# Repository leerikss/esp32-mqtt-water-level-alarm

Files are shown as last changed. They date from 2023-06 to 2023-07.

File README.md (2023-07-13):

# esp32-mqtt-water-level-alarm

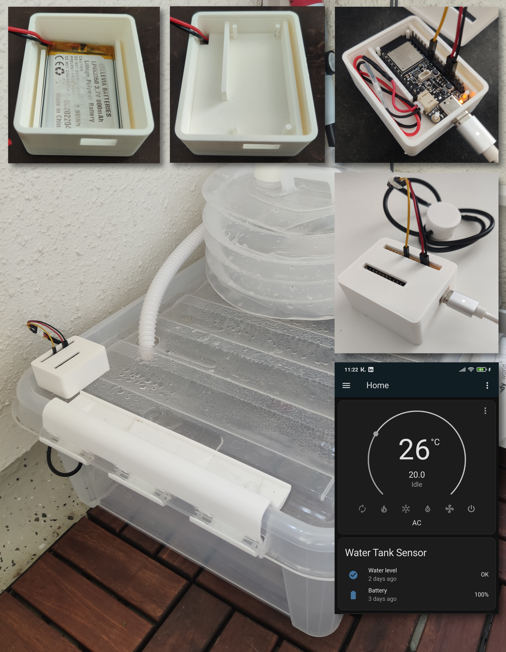
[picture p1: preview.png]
Device in actin with a 3D printed enclosure


I have a water tank on my balcony collecting condensation water from the AC.
To prevent potential water overflow, I made a little system that shuts down the AC if the tank gets too full.
The system consists of
1) an esp32 board with a liquid level sensor powered by a LiPo battery, sending MQTT messages to a
2) <a href="https://www.home-assistant.io/">HomeAssistant OS</a> running on a <a href="https://www.raspberrypi.org/">Raspberry PI</a>, which in turn shuts down the AC upon critical water level

## Hardware

### ESP32 board
Adafruit ESP32-S3 Feather (https://learn.adafruit.com/adafruit-esp32-s3-feather/overview)

### Liquid level sensor
Crowtail- Non-contact liquid level sensor 2.0 (https://www.elecrow.com/crowtail-noncontact-liquid-level-sensor-p-1656.html)

### Battery
A Li-Po battery 3,7V 800mAh 

## C++ notes
To compile, add and edit the "src/secrets.h" file with your wifi/mqtt secrets. 
There's a "secrets.h.example" file with required definitions.

## Home assistant integration
This is how I've configured HomeAssistant

### configuration.yaml (adds two mqtt sensors)

~~~code
...
mqtt:
  sensor:
    - name: "Water Tank Sensor Battery"
      unique_id: "water-tank-sensor-battery"
      state_topic: "/home/balcony/watertank/sensor"
      json_attributes_topic: "/home/balcony/watertank/sensorr"
      value_template: "{{ value_json.battery }}"
      json_attributes_template: "{{ value_json.battery | tojson }}"
      unit_of_measurement: "%"
      device_class: "battery"
  binary_sensor:
    - name: "Water Tank Sensor Alarm"
      unique_id: "water-tank-sensor-alarm"
      state_topic: "/home/balcony/watertank/sensor"
      json_attributes_topic: "/home/balcony/watertank/sensor"
      value_template: "{{ value_json.full }}"
      json_attributes_template: "{{ value_json.full | tojson }}"
      payload_on: true
      payload_off: false
      device_class: "problem"
...
~~~

### Automation configuration example

~~~code
alias: Turn Off AC when watertank is full
description: ""
trigger:
  - platform: state
    entity_id:
      - binary_sensor.water_tank_sensor_alarm
    to: "on"
condition: []
action:
  - repeat:
      while:
        - condition: state
          entity_id: binary_sensor.water_tank_sensor_alarm
          state: "on"
      sequence:
        - device_id: 0b4465ab94e18bb160c19ce772ebd205
          domain: climate
          entity_id: climate.ac
          type: set_hvac_mode
          hvac_mode: "off"
        - delay:
            minutes: 1
mode: single
~~~

## 3D enclosure
The 3D enclosure STL and OpenSCAD files can be found in the "3d-enclosure" folder. The enclosure is a modified version of the <a href="https://www.thingiverse.com/thing:2411898">box with snap on cover - parametrised OpenSCAD</a>.

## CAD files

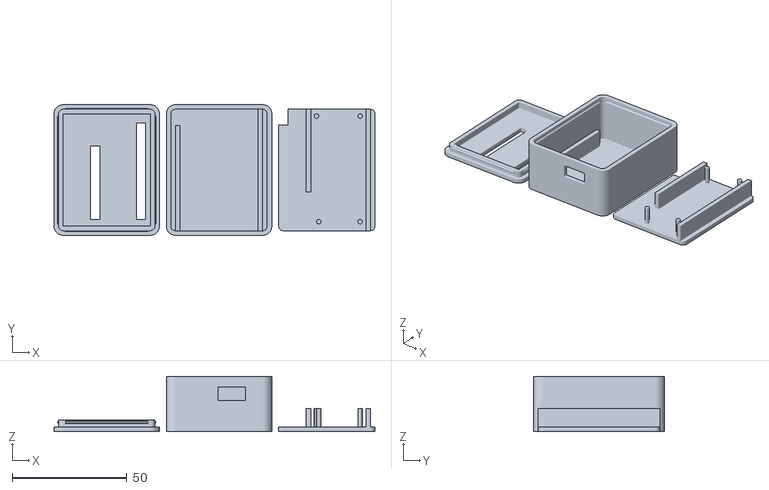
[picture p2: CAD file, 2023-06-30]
3d-enclosure/enclosure.stl
140.0 x 57.0 x 24.0

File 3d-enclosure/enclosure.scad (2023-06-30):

// V 1.2 Correction / hint from molotok3D, some minor fixes
// V 1.1- added opening helper and an optional separating wall

wi=42;	// inner width, length & heigth
li=53;
th=2;	// wall thickness
h=8+th+12;
r=2;	// radius of rounded corners
opening_help=false;	// make a gap to ease opening of the cover, f.ex.
		// with a coin - girls are afraid of their finger nails ;-)

e=0.01;
ri=(r>th)?r-th:e;	// needed for the cover - needs to be larger than 0 for proper results
l=li-2*r;
w=wi-2*r;

// Custom sizes
battery_w = 34;
battery_h = 52;

board_w = 24;
board_h = 52;

bar_h = 8;
bar_r_off = 2;
pole_w = 1;

$fn=100; // Roundness

module box(){
	difference(){
		translate([0,0,-th])hull(){
			for (i=[[-w/2,-l/2],[-w/2,l/2],[w/2,-l/2],[w/2,l/2]]){
				translate(i)cylinder(r=r+th,h=h+th);
			}
		}
		hull(){
			for (i=[[-w/2,-l/2],[-w/2,l/2,],[w/2,-l/2],[w/2,l/2]]){
				translate(i)cylinder(r=r,h=h+0.1);
			}
		}
		translate([-w/2,l/2+r,h-2])rotate([0,90,0])cylinder(d=1.2,h=w);
		translate([-w/2,-l/2-r,h-2])rotate([0,90,0])cylinder(d=1.2,h=w);
		translate([w/2+r,l/2,h-2])rotate([90,0,0])cylinder(d=1.2,h=l);
		translate([-w/2-r,l/2,h-2])rotate([90,0,0])cylinder(d=1.2,h=l);

        usb_hole();
        
		// if you need some adjustment for the opening helper size or position,
		// this is the right place
		if (opening_help)translate([w/2-10,l/2+13.5,h-1.8])cylinder(d=20,h=10);
	}
}

module usb_hole() {
    translate([-0.5
    , -li/2-th-1, 11.5]) 
    linear_extrude(6) {
        square([12, th+2]);
    }
}

module bar(x,y,len){
    translate([x, y, 0])
    linear_extrude(bar_h) {
        square([th, len]);
    }
    
}

module box_bars() {
    // Battery right bar
    x = wi/2 - th - bar_r_off;
    bar(x, -li/2, li);

    // Battery left bar
    bar(x - battery_w - th, -li/2, li - 7);
}

module board_layer()  {
    difference() {
    
        translate([0,0,-th])hull(){
            for (i=[[-w/2,-l/2],[-w/2,l/2],[w/2,-l/2],[w/2,l/2]]){
                translate(i)cylinder(r=r,h=th);
            }
        }
    
        translate([-wi/2-e, li/2-6.9, -th-1]) linear_extrude(th+2) {
            square([4, 7]);
        }
    }
}

module board_layer_bars() {
    // Board right bar
    x = wi/2 - th - bar_r_off;
    bar(x, -li/2, li);

    // Board left bar
    bar(x - board_w - th, -th - 7.5, 36);
}

module pole(x, y) {
   translate([x, y, 0]) {
       cylinder(bar_h, pole_w, pole_w);
   }
}

module board_layer_poles() {
   x1 = wi/2 - th - pole_w - bar_r_off - 1.5;
   y1 = li/2 - th/2 - 2;
   pole(x1, y1);
   
   x2 = x1 - 19;
   pole(x2, y1);
    
   x3 = x1;
   y3 = y1 - 46;
   pole(x3, y3);
   
   x4 = x3 - 18;
   pole(x4, y3);
}

module cover(){
	difference(){
        translate([0,0,-th])hull(){
            for (i=[[-w/2,-l/2],[-w/2,l/2],[w/2,-l/2],[w/2,l/2]]){
                translate(i)cylinder(r=r+th,h=th);
            }
        }
        pin_holes();
    }
    
	difference(){
		translate([0,0,-th])hull(){
			for (i=[[-w/2,-l/2],[-w/2,l/2],[w/2,-l/2],[w/2,l/2]]){
				translate(i)cylinder(r=r,h=th+3);
			}
		}
		hull(){
			for (i=[[-w/2,-l/2],[-w/2,l/2],[w/2,-l/2],[w/2,l /2]]){
				if (r>th){
					translate(i)cylinder(r=r-th,h=3+e);
				}else{
					translate(i)cylinder(r=e,h=3+e);
				}
			}
		}
        pin_holes();
	}
	translate([-w/2+1,l/2+r-0.2,2])rotate([0,90,0])cylinder(d=1.2,h=w-2);
	translate([-w/2+1,-l/2-r+0.2,2])rotate([0,90,0])cylinder(d=1.2,h=w-2);
	translate([w/2+r-0.2,l/2-1,2])rotate([90,0,0])cylinder(d=1.2,h=l-2);
	translate([-w/2-r+0.2,l/2-1,2])rotate([90,0,0])cylinder(d=1.2,h=l-2);

}

// Holes for the pins
module pin_holes() {
    hole_w = 4;
    hole1_len = 42;
    hole2_len = 32;
    
    // Hole1
    x1 = wi/2 - bar_r_off - th - hole_w;
    y1 = -hole1_len/2 - 0.5;
    translate([x1,y1,-th*2]) linear_extrude(th*3) {
        square([hole_w, hole1_len]);
    }
    
    // Hole2
    x2 = x1 - 20;
    y2 = y1;
    translate([x2,y2,-th*2]) linear_extrude(th*3) {
        square([hole_w, hole2_len]);
    }
}

module print_part() {
    // Box
    box();
    box_bars();

    // Board layer
    translate([wi + th + 3, 0, 0]) {
    // translate([0, 0, th + bar_h]) {
        board_layer();
        board_layer_bars();
        board_layer_poles();
    }
    
    // Cover
    // translate([0,li+3+2*th,0]) cover(); // "real" position
    translate([-wi-3-2*th,0,0]) cover();
}

// For 2D print (Render, export to SVG and open with Inkscape)
// projection(cut = true) translate([0,0,-1]) print_part();
// projection(cut = true) translate([0,0,0]) print_part();

print_part();

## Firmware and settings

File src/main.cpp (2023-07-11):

#include <Arduino.h>
#include <cmath>

#include <WiFi.h>
#include <Ticker.h>
#include <AsyncMqttClient.h>

#include <Wire.h>
#include <SparkFun_MAX1704x_Fuel_Gauge_Arduino_Library.h> 

#include <secrets.h>

// in & out pins
#define WATER_SENSOR_OUT_PIN  A0
#define WATER_SENSOR_IN_PIN   A5

#define SLEEP_IN_SECONDS      300 // 5 min sleep time in seconds after message has been delivered
#define BATTERY_CHANGE_RATE   5   // 100%, 95%, 90%, ...

// Create a secrets.h file with these values defined (look at the secrets.h.example file)
char      wifi_ssid[] =             WIFI_SSID;
char      wifi_password[] =         WIFI_PASSWORD;
char      mqtt_broker_ip[] =        MQTT_BROKER_IP;
uint16_t  mqtt_broker_port =        MQTT_BROKER_PORT;
char      mqtt_broker_username[] =  MQTT_BROKER_USERNAME;
char      mqtt_broker_password[] =  MQTT_BROKER_PASSWORD;
char      mqtt_topic[] =            MQTT_TOPIC;
char      mqtt_client_id[] =        MQTT_CLIENT_ID;

SFE_MAX1704X lipo(MAX1704X_MAX17048); 
AsyncMqttClient mqtt_client;
Ticker wifi_reconnect_timer;
Ticker mqtt_reconnect_timer;
char json_buffer[64];

RTC_DATA_ATTR signed int  prev_liquid_detected = -1;
RTC_DATA_ATTR signed int  prev_battery_percent1 = -1;
RTC_DATA_ATTR signed int  prev_battery_percent2 = -1;

int read_battery_percent(int nearest_n) {
  while(!Wire.available() && !Wire.begin()) {
    delay(10);
  }
  while (!lipo.begin()) {
    delay(10);
  }
  lipo.quickStart(); // Should we run this every time?
  return static_cast<int>(round(lipo.getSOC() / nearest_n) * nearest_n);
}

void go_to_sleep() {
  Serial.printf("Going to deep sleep for %d seconds..\n", SLEEP_IN_SECONDS);
  esp_sleep_enable_timer_wakeup(SLEEP_IN_SECONDS * 1000000);
  esp_deep_sleep_start(); 
}

void connect_to_mqtt() {
  Serial.println("Connecting to the mqtt broker...");
  mqtt_client.connect();
}

void mqtt_event_connected(bool session_present) {
  Serial.printf("Connected to mqtt broker, publishing %s\n", json_buffer);
  mqtt_client.publish(MQTT_TOPIC, 1, true, json_buffer); // Using QoS 1 to retrieve acknowledgement..
}

void mqtt_event_disconnected(AsyncMqttClientDisconnectReason reason) {
  Serial.println("Disconnected from the mqtt broker.");
  if (WiFi.isConnected()) {
    mqtt_reconnect_timer.once(2, connect_to_mqtt);
  }  
}

void mqtt_event_published(uint16_t packet_id) {
  go_to_sleep();
}

void setup_mqtt() {
  mqtt_client.onConnect(mqtt_event_connected);
  mqtt_client.onDisconnect(mqtt_event_disconnected);
  mqtt_client.onPublish(mqtt_event_published);
  mqtt_client.setServer(mqtt_broker_ip, mqtt_broker_port);
  mqtt_client.setCredentials(mqtt_broker_username, mqtt_broker_password);
}

void connect_to_wifi() {
  Serial.println("Connecting to Wi-Fi...");
  WiFi.begin (wifi_ssid, wifi_password);
}

void wifi_event_connected(WiFiEvent_t event, WiFiEventInfo_t info) {
  Serial.println("Connected to Wi-Fi");
  connect_to_mqtt();
}

void wifi_event_disconnected(WiFiEvent_t event, WiFiEventInfo_t info) {
  Serial.println("Disconnected from Wi-Fi.");
  mqtt_reconnect_timer.detach(); // ensure we don't reconnect to MQTT while reconnecting to Wi-Fi
  wifi_reconnect_timer.once(2, connect_to_wifi);
}

void setup_wifi() {
  WiFi.onEvent(wifi_event_connected, WiFiEvent_t::ARDUINO_EVENT_WIFI_STA_GOT_IP);
  WiFi.onEvent(wifi_event_disconnected, WiFiEvent_t::ARDUINO_EVENT_WIFI_STA_DISCONNECTED);
}

const void set_message(boolean liquid_detected, int battery_percent) {
  snprintf(json_buffer, 64, "{\"full\": %s, \"battery\": %i }", 
    (liquid_detected) ? "true" : "false", battery_percent);
  json_buffer[sizeof(json_buffer) - 1] = '\0';
}

void publish_message(boolean liquid_detected, int battery_percent) {
  set_message(liquid_detected, battery_percent);
  setup_wifi();
  setup_mqtt();
  connect_to_wifi(); // Starts async message submission process
}

void setup () {

  setCpuFrequencyMhz(80); // Save power
  Serial.begin (115200);

  pinMode(WATER_SENSOR_OUT_PIN, OUTPUT);
  pinMode(WATER_SENSOR_IN_PIN, INPUT_PULLUP);

  digitalWrite(WATER_SENSOR_OUT_PIN, HIGH);
  delay(500); // Allow the sensor to stabilize
  boolean liquid_detected = (digitalRead(WATER_SENSOR_IN_PIN) == 0);
  digitalWrite(WATER_SENSOR_OUT_PIN, LOW);

  int battery_percent = read_battery_percent(BATTERY_CHANGE_RATE);

  // Preserve battery by not doing networking if values are unchanged
  if(liquid_detected == prev_liquid_detected && 
    (battery_percent == prev_battery_percent1 || 
    battery_percent == prev_battery_percent2)) {
    go_to_sleep();
  }

  // Persist values - we persist and check against two last battery values, as the battery value
  // fluctuates between two values when close to limit values, no need to waste battery by reporting that
  prev_liquid_detected = liquid_detected;
  prev_battery_percent2 = (prev_battery_percent1 == -1) ? battery_percent : prev_battery_percent1;
  prev_battery_percent1 = battery_percent;

  publish_message(liquid_detected, battery_percent);
}

void loop () {
}

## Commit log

2023-06-11 General improvements & optimizations - Change to use the AsyncMqttClient for more reliable async wifi & mqtt operations - Publish MQTT message with QoS level 1 for retrieving message delivery acknole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
2023-06-11 Change HomeAssistant automation to turn off the AC in a loop as long as the water level is too high.
    [main.cpp]
2023-06-15 Battery optimization changes
2023-06-16 Add a 3D-enclosure for the project (OpenSCAD format + STL-file).
    [enclosure_snap.scad, enclosure_snap.stl]
2023-06-16 Fix mirror imaged top lock bug
    [enclosure_snap.scad, enclosure_snap.stl]
2023-06-20 Fix liquid detection change not always being published
    [main.cpp]
2023-06-26 Add small note about the 3D enclosure
2023-06-30 Add a new smaller version of the 3D enclosure, where the battery is positioned below the board. Update the preview image.
    [enclosure.scad, enclosure.stl, enclosure_snap.scad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]
2023-06-30 Update the README.MD as the enclosure is based on another OpenSCAD file.
2023-07-11 Fix battery percentage being reported too often when close to a limit value, draiining battery unnecessarily
    [main.cpp]
